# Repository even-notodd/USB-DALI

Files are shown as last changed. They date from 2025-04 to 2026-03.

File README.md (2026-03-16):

# USB-DALI
USB-DALI adapter. The device works as a gateway allowing sending data via USB VCP (USB Virtual COM Port) to DALI bus and reading data from DALI bus via Modbus RTU protocol. The device can be operated via standard Modbus RTU commands set. Data exchange examples can be found in the repo. Hardware includes DALI bus power supply. Software includes C# sample of sending basic DALI commands including DALI configuration and a simple GUI.

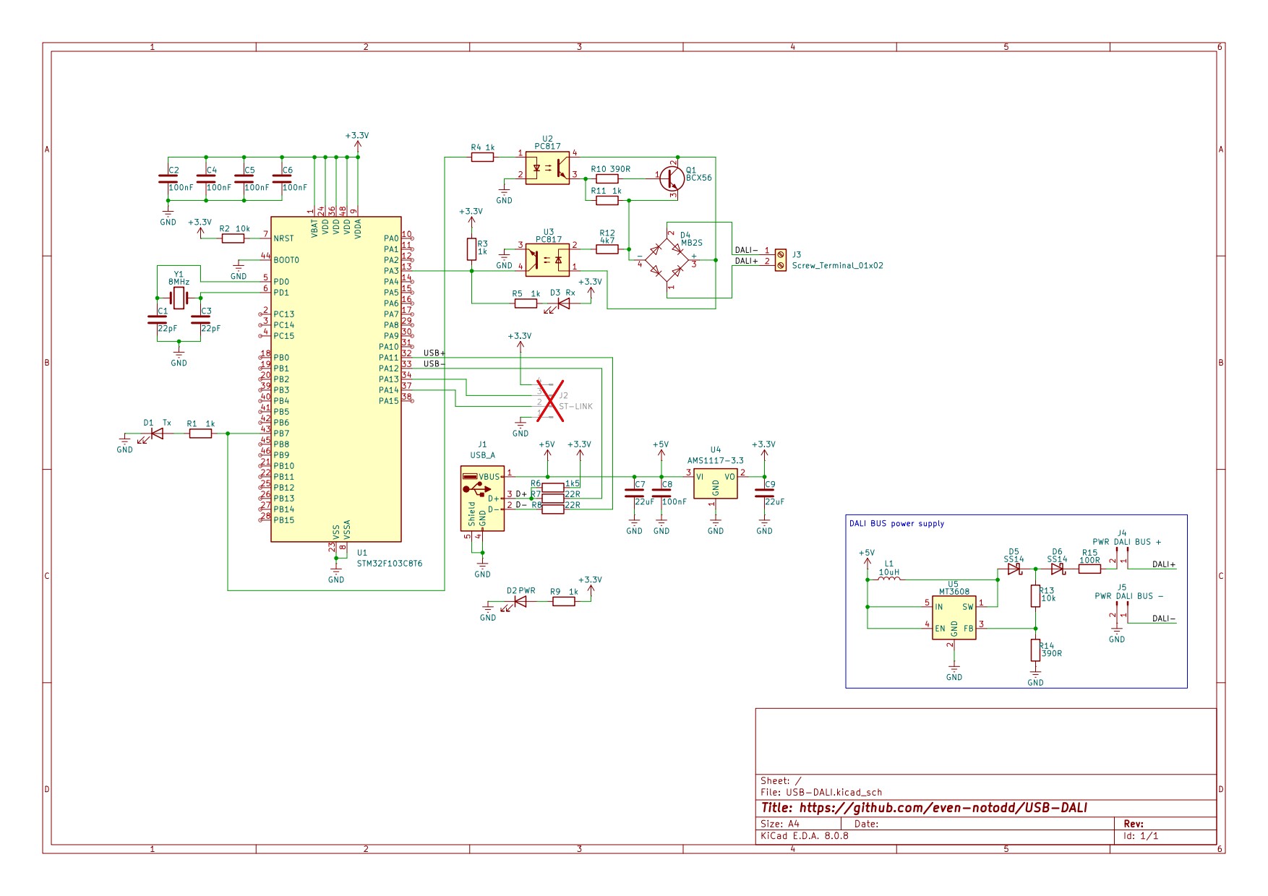
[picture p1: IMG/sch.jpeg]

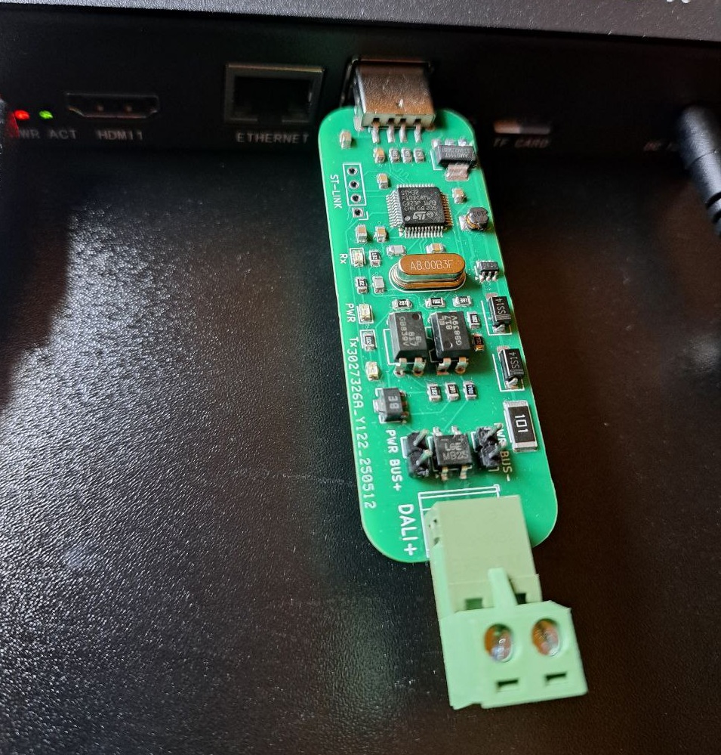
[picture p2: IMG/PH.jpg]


## Hardware
This design has been tested before and successfully used in several systems. 
The device is built around popular STM32F103C8T6 using MCUs USB. The DALI "physical layer" is build with a few discrete components without any special transceiver.
The hardware implementation also includes DALI bus power supply which simplifies its usage in building hardware setups through design & development process. Nevertheless we don't recommend (!) using it as bus power supply in any permanent installations.

The module can work with DALI line powered from external DALI power supply or powered from 
own built-in 16V 160mA converter (powered from USB). If you are planning to use external power supply 
it’s important to open 2 jumpers on the board before connection the module to DALI network and USB. Do 
not use 2 power supplies (external and internal) at the same time! While working with both of jumpers
 open (external power supply), the module provides galvanic isolation between USB and DALI, but when 
powered from built-in power supply, DALI line has not galvanic isolation from USB.
 Being connected to USB, the module can be found in operating system as virtual COM port. It’s 
important to admit, that after connection to that port from the software, it takes MCU some time to create 
stable connection so it’s recommended to keep 3-5 seconds pause between connection and start of data 
exchange.

## Software
The software is a demo GUI providing simple access to direct and indirect commands in DALI network (like broadcasting of brightness, working with individual addresses etc).
Visual Studio Community Edition can be used to build or modify.

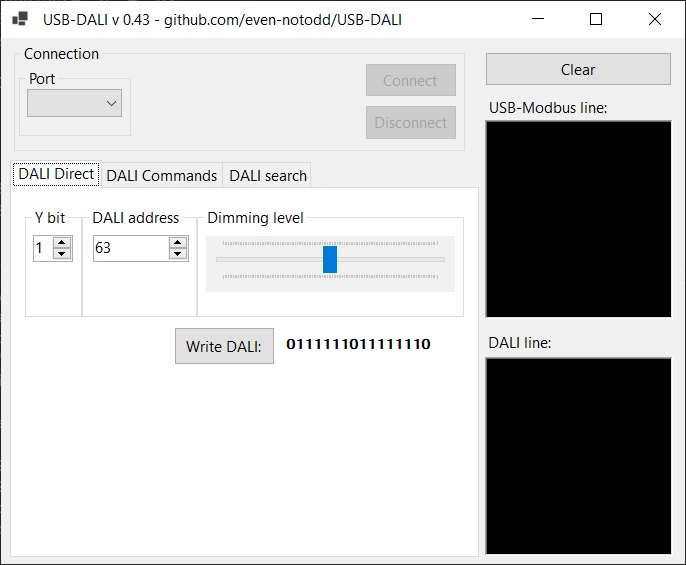
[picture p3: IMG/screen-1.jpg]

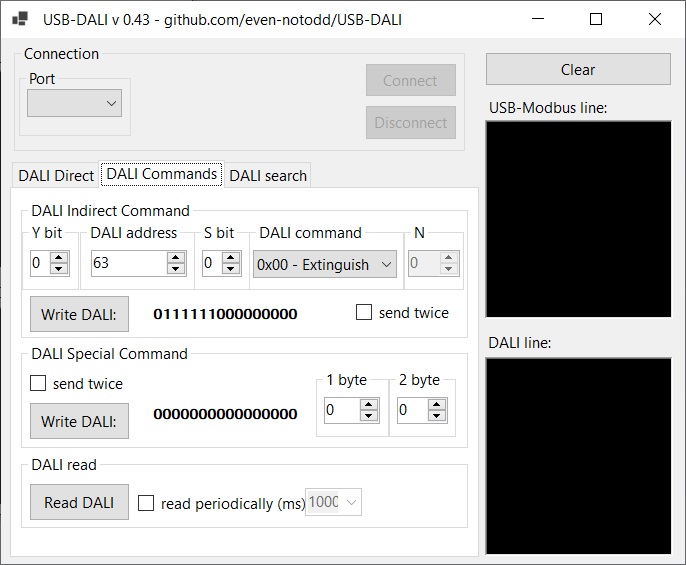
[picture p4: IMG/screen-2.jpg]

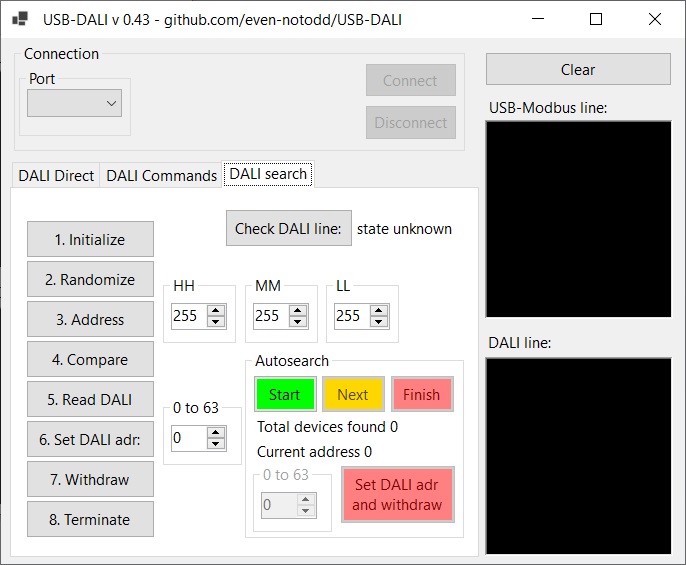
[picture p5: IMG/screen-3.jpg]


## Drivers & settings
The device works as VCP (Virtual COM Port). When using with Linux - no drivers required. For Windows - [VCP driver](https://www.st.com/en/development-tools/stsw-stm32102.html) from ST Microelectronics should be used.
 The Modbus address of the USB-DALI module is 0x01 (not changeable). As far as there is no possibility to connect other devices to the same USB VCP, it will be always the only device in created 
Modbus network.

## Firmware
Firmware file can be found in corresponding sub-folder and can be flashed to MCU with ST-Link (optionally J-Link).

## Protocol
For protocol description and examples look inside Protocol.pdf 

## License
See the LICENSE file for details.

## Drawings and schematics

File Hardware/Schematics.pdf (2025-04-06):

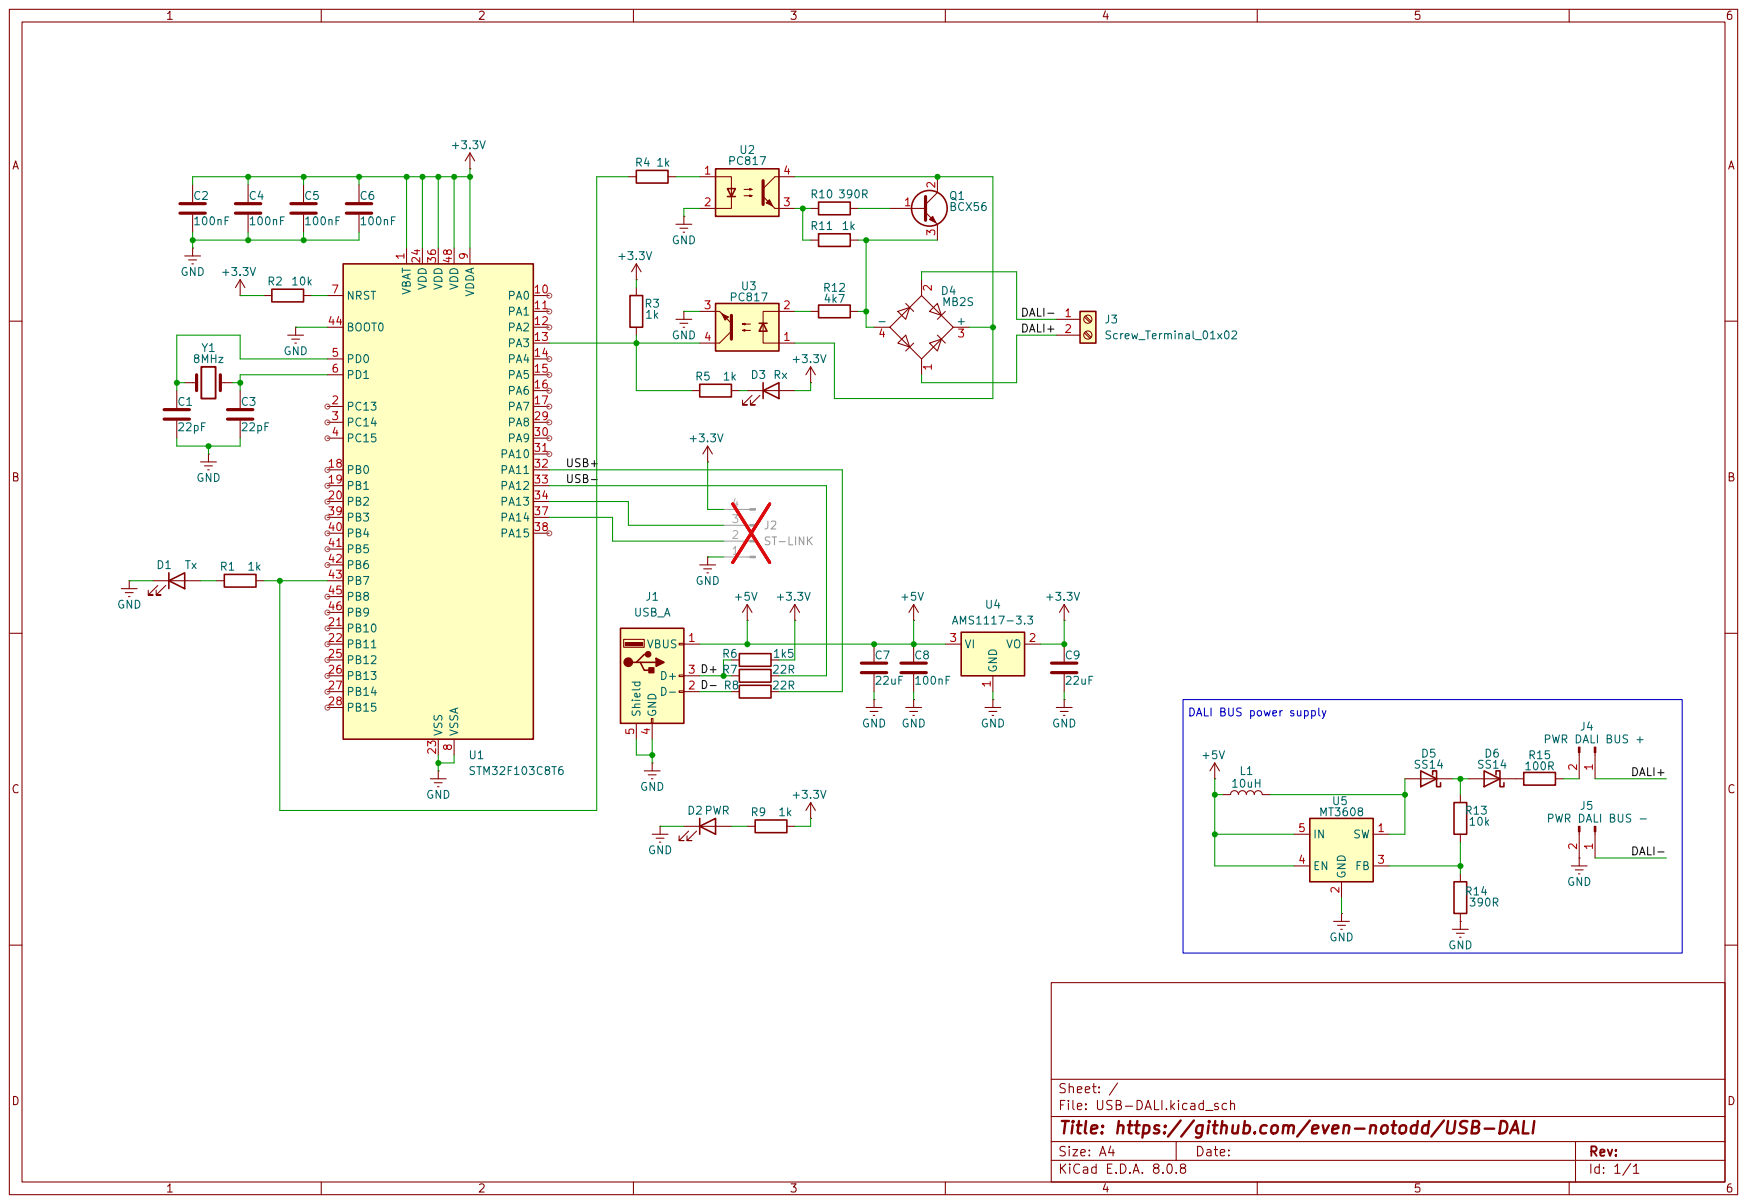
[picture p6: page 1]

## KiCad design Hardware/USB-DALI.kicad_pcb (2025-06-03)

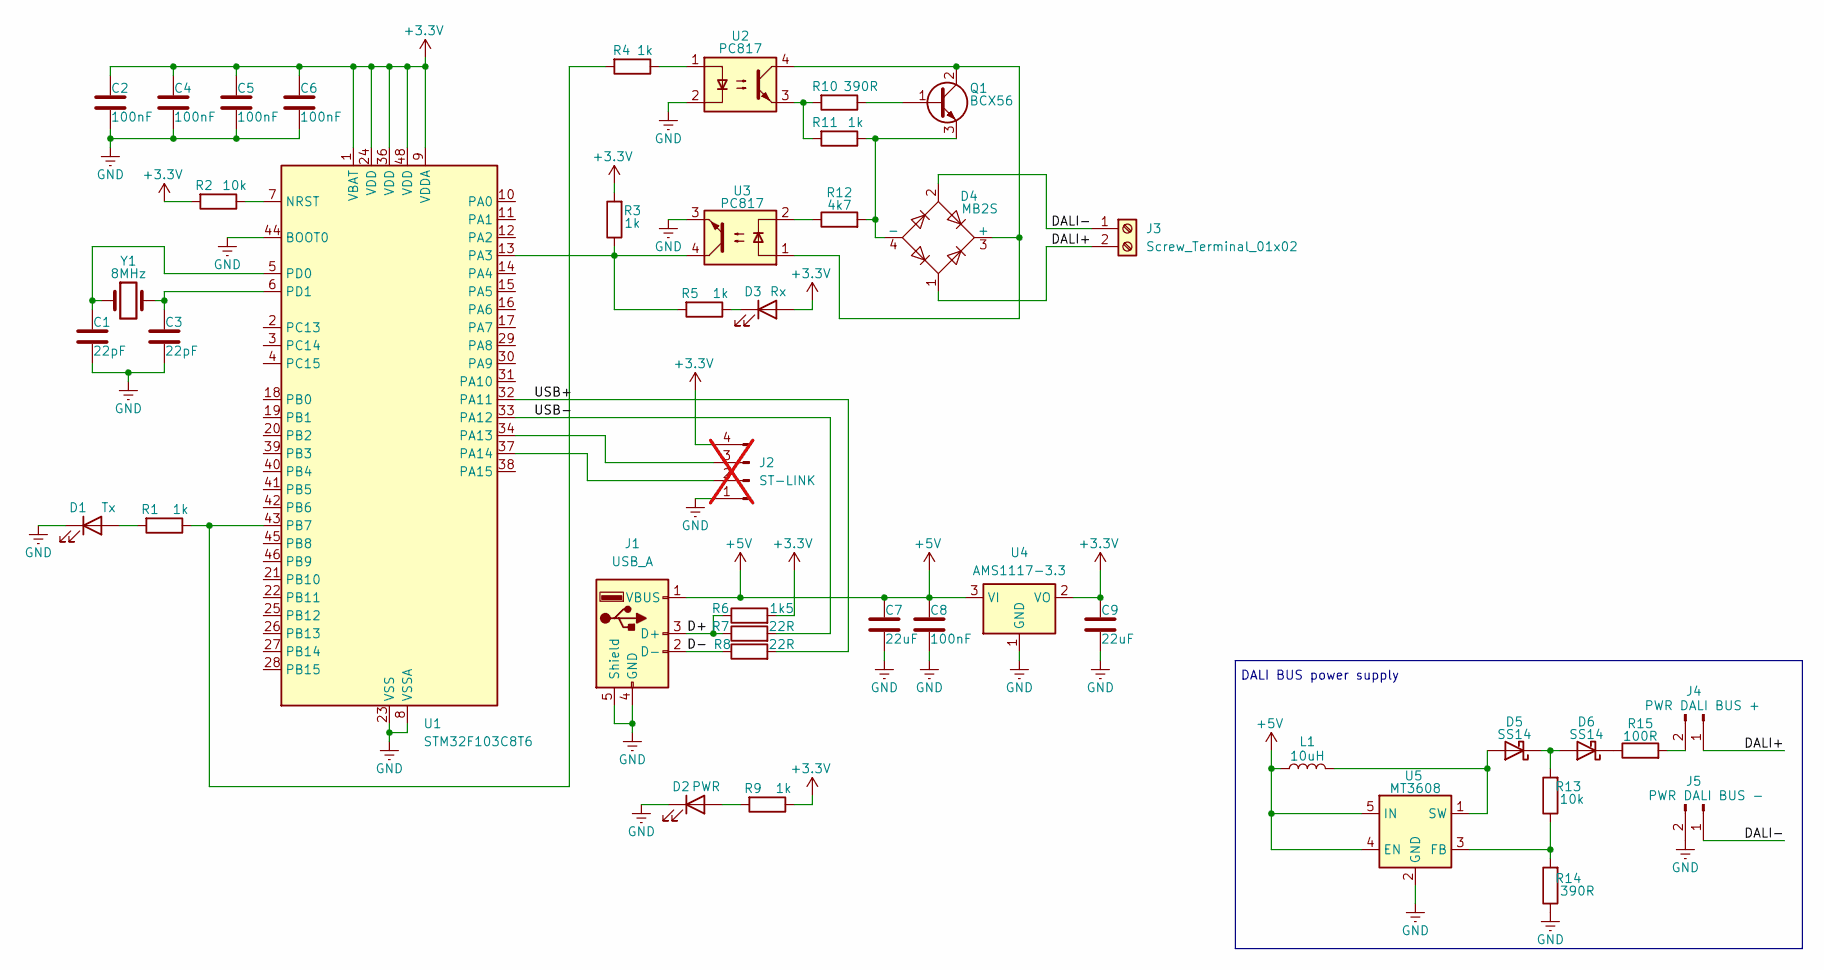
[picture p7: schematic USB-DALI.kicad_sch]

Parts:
C1, C3: 22pF; C_0805_2012Metric
C2, C4, C5, C6, C8: 100nF; C_0805_2012Metric
C7, C9: 22uF; C_0805_2012Metric
D1: Tx; LED_0805_2012Metric
D2: PWR; LED_0805_2012Metric
D3: Rx; LED_0805_2012Metric
D4: MB2S; TO-269AA
D5, D6: SS14; D_SMA
J1: USB_A; USB_A_CNCTech_1001-011-01101_Horizontal
J2: ST-LINK; PinHeader_1x04_P2.54mm_Vertical; not fitted
J3: Screw_Terminal_01x02; TerminalBlock_Phoenix_MKDS-1,5-2-5.08_1x02_P5.08mm_Horizont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
J4: PWR DALI BUS +; PinHeader_1x02_P2.54mm_Vertical
J5: PWR DALI BUS -; PinHeader_1x02_P2.54mm_Vertical
L1: 10uH; L_1210_3225Metric
Q1: BCX56; SOT-89-3
R1, R3, R4, R5, R9, R11: 1k; R_0805_2012Metric
R2, R13: 10k; R_0805_2012Metric
R6: 1k5; R_0805_2012Metric
R7, R8: 22R; R_0805_2012Metric
R10, R14: 390R; R_0805_2012Metric
R12: 4k7; R_0805_2012Metric
R15: 100R; R_2512_6332Metric
U1: STM32F103C8T6; LQFP-48_7x7mm_P0.5mm
U2, U3: PC817; DIP-4_W7.62mm
U4: AMS1117-3.3; SOT-223-3_TabPin2
U5: MT3608; SOT-23-6
Y1: 8MHz; Crystal_HC49-U_Vertical

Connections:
+3.3V: C2.1, C4.1, C5.1, C6.1, C9.1, D3.2 (A), J2.4, R2.2, R3.2, R6.2, R9.1, U1.1 (VBAT), U1.9 (VDDA), U1.24 (VDD), U1.36 (VDD), U1.48 (VDD), U4.2 (VO)
+5V: C7.1, C8.1, J1.1 (VBUS), L1.1, U4.3 (VI), U5.4 (EN), U5.5 (IN)
/D+: J1.3 (D+), R6.1, R7.1
/D-: J1.2 (D-), R8.1
/DALI+: D4.1, J3.2, J4.1
/DALI-: D4.2, J3.1, J5.1
/USB+: R8.2, U1.32 (PA11)
/USB-: R7.2, U1.33 (PA12)
GND: C1.2, C2.2, C3.2, C4.2, C5.2, C6.2, C7.2, C8.2, C9.2, D1.1 (K), D2.1 (K), J1.4 (GND), J1.5 (Shield), J2.1, J5.2, R14.1, U1.8 (VSSA), U1.23 (VSS), U1.35 (VSS), U1.44 (BOOT0), U1.47 (VSS), U2.2, U3.3, U4.1 (GND), U5.2 (GND)
unnamed: D1.2 (A), R1.2
unnamed: D2.2 (A), R9.2
unnamed: D3.1 (K), R5.1
unnamed: D4.3 (+), Q1.2 (C), U2.4, U3.1
unnamed: D4.4 (-), Q1.3 (E), R11.1, R12.2
unnamed: D5.2 (A), L1.2, U5.1 (SW)
unnamed: D5.1 (K), D6.2 (A), R13.2
unnamed: D6.1 (K), R15.1
unnamed: J2.2, U1.37 (PA14)
unnamed: J2.3, U1.34 (PA13)
unnamed: J4.2, R15.2
unnamed: Q1.1 (B), R10.1
unnamed: R4.1, U2.1
unnamed: R10.2, R11.2, U2.3
unnamed: R12.1, U3.2
unnamed: R2.1, U1.7 (NRST)
unnamed: R3.1, R5.2, U1.13 (PA3), U3.4
unnamed: R1.1, R4.2, U1.43 (PB7)
unnamed: C1.1, U1.5 (PD0), Y1.1
unnamed: C3.1, U1.6 (PD1), Y1.2
unnamed: R13.1, R14.2, U5.3 (FB)

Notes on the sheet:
DALI BUS power supply

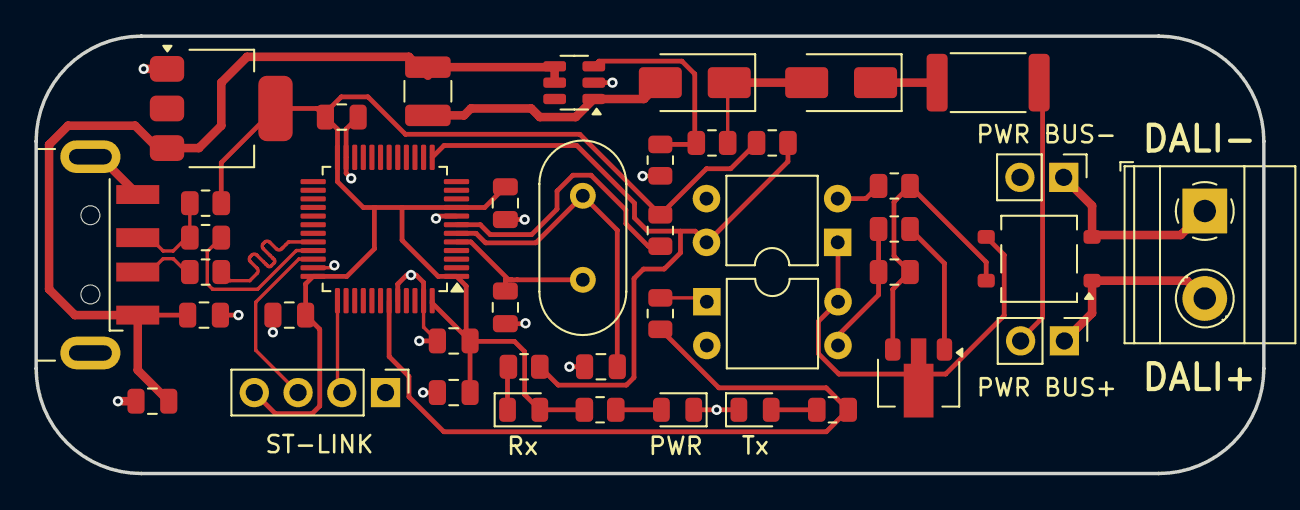
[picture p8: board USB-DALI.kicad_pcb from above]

Board: 2 copper layers, 71.3 x 25.4 mm, 43 parts (0 on the bottom side), 30 nets.

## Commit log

2025-03-23 a silk fix & gerbers
    [USB-DALI-B_Cu.gbr, USB-DALI-B_Mask.gbr, USB-DALI-B_Paste.gbr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]
2025-04-06 Schematics in pdf and link to win driver added
    [USB-DALI.kicad_sch]
2025-06-03 USB connector MPN
    [USB-DALI.kicad_pcb]
2026-03-07 Schematics as JPG added
